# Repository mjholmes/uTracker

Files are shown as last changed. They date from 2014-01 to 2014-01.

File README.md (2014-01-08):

# uTracker - a micro RF tracker for HAB use

This tracker builds on the basic tracker i built about a year ago. It is based on an Arduino 328 and uses a bespoke PCB with surface mount components to achiever a much smaller form factor than the previous basic tracker.

The board makes use of a dc/dc step up converter providing 3.3v from a single AA/AAA battery. Unusually for smaller boards this uses the NTX2 / NTX2b for the RF transmitter.

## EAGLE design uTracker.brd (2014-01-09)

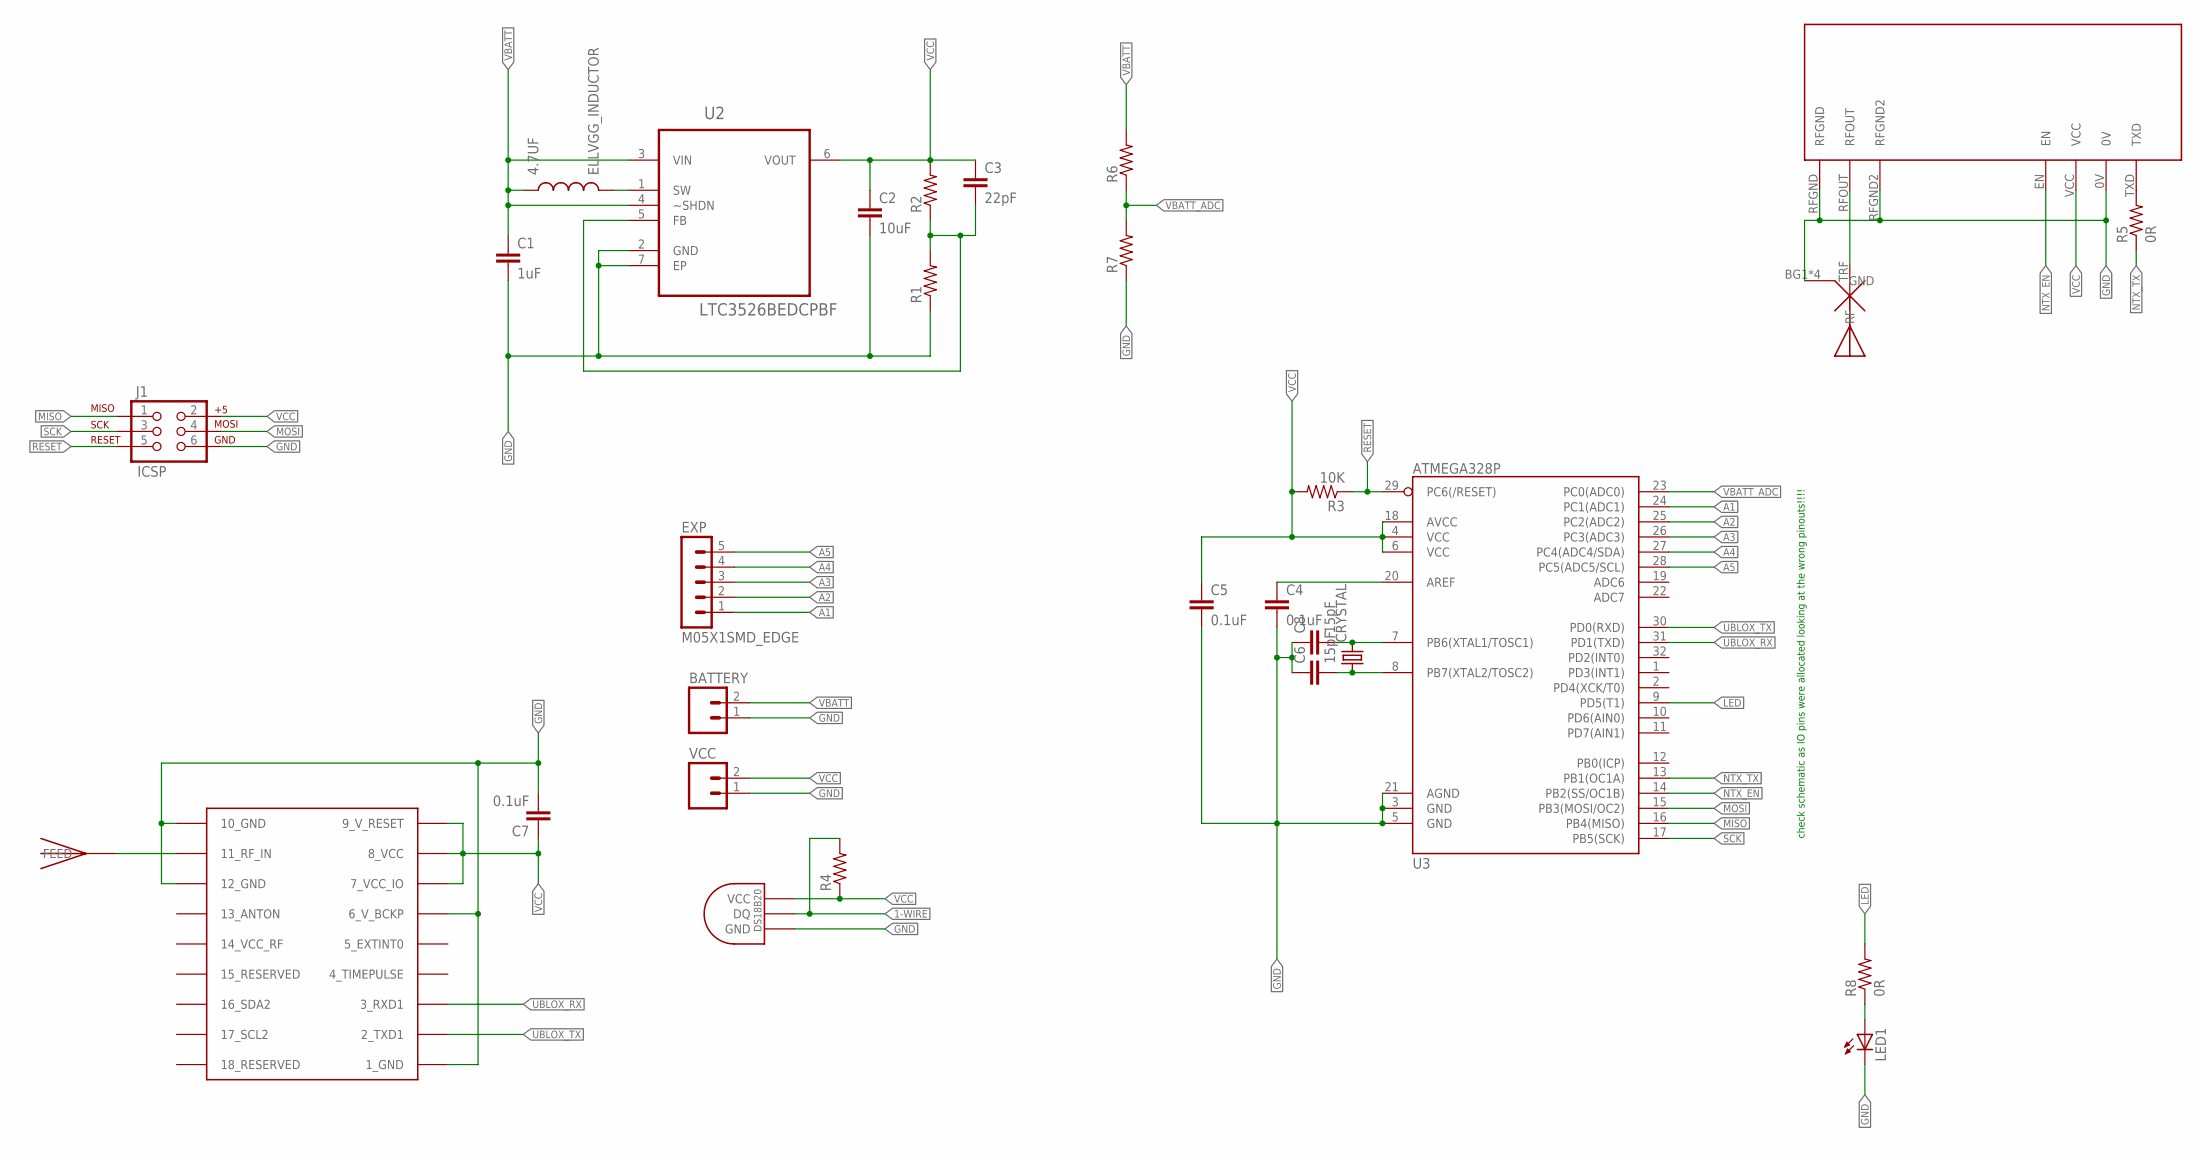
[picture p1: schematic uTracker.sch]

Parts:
4.7UF: ELLVGG_INDUCTOR
BATTERY: M02PTH; 1X02
C1: 1uF; 0805
C2: 10uF; 0805
C3: 22pF; 0805
C4, C5, C7: 0.1uF; 0805
C6, C8: 15pF; 0805
CRYSTAL: ABRACON_ABM3_CRYSTALABM03_HC49; ABM03_HC49
EXP: M05X1SMD_EDGE; M05_SMD_EDGE
J1: ICSP; ICSP_SMD_EDGE
LED1: LED1206; LED-1206
R1, R2, R4, R6, R7: RESISTOR0805-RES; 0805
R3: 10K; 0805
R5, R8: 0R; 0805
U2: LTC3526BEDCPBF; DFN200X200X80-7N
U3: ATMEGA328P; TQFP32-08
U$1: ANTENNA; ANTCONN_GNDPL
U$2: JTI_ANTENNA-1575AT43A40
U$3: NTX2
U$4: DS1820SOIC; DS18B20_SOIC
UBLOX: UBLOX_MAX-6
VCC: M02PTH; 1X02

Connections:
1-WIRE: R4.2, U$4.DQ
A1: EXP.1, U3.24 (PC1(ADC1))
A2: EXP.2, U3.25 (PC2(ADC2))
A3: EXP.3, U3.26 (PC3(ADC3))
A4: EXP.4, U3.27 (PC4(ADC4/SDA))
A5: EXP.5, U3.28 (PC5(ADC5/SCL))
GND: BATTERY.1, C1.2, C2.2, C4.2, C5.2, C6.1, C7.2, C8.1, J1.6, LED1.C, R1.1, R7.1, U2.2 (GND), U2.7 (EP), U3.3 (GND), U3.5 (GND), U3.21 (AGND), U$1.BG1 (GND), U$1.BG2 (GND), U$1.TG1 (GND), U$1.TG2 (GND), U$3.0V, U$3.RFGND, U$3.RFGND2, U$4.GND, UBLOX.1_GND, UBLOX.6_V_BCKP, UBLOX.10_GND, UBLOX.12_GND, VCC.1
LED: R8.2, U3.9 (PD5(T1))
MISO: J1.1, U3.16 (PB4(MISO))
MOSI: J1.4, U3.15 (PB3(MOSI/OC2))
unnamed: C3.2, R1.2, R2.1, U2.5 (FB)
unnamed: U$2.FEED, UBLOX.11_RF_IN
unnamed: 4.7UF.P$2 (2), U2.1 (SW)
unnamed: C4.1, U3.20 (AREF)
unnamed: R5.2, U$3.TXD
unnamed: C8.2, CRYSTAL.2, U3.7 (PB6(XTAL1/TOSC1))
unnamed: C6.2, CRYSTAL.1, U3.8 (PB7(XTAL2/TOSC2))
unnamed: U$1.TRF (RF), U$3.RFOUT
unnamed: LED1.A, R8.1
NTX_EN: U3.14 (PB2(SS/OC1B)), U$3.EN
NTX_TX: R5.1, U3.13 (PB1(OC1A))
RESET: J1.5, R3.1, U3.29 (PC6(/RESET))
SCK: J1.3, U3.17 (PB5(SCK))
UBLOX_RX: U3.31 (PD1(TXD)), UBLOX.3_RXD1
UBLOX_TX: U3.30 (PD0(RXD)), UBLOX.2_TXD1
VBATT: 4.7UF.P$1 (1), BATTERY.2, C1.1, R6.2, U2.3 (VIN), U2.4 (~SHDN)
VBATT_ADC: R6.1, R7.2, U3.23 (PC0(ADC0))
VCC: C2.1, C3.1, C5.1, C7.1, J1.2, R2.2, R3.2, R4.1, U2.6 (VOUT), U3.4 (VCC), U3.6 (VCC), U3.18 (AVCC), U$3.VCC, U$4.VCC, UBLOX.7_VCC_IO, UBLOX.8_VCC, UBLOX.9_V_RESET, VCC.2

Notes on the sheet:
check schematic as IO pins were allocated looking at the wrong pinouts!!!!

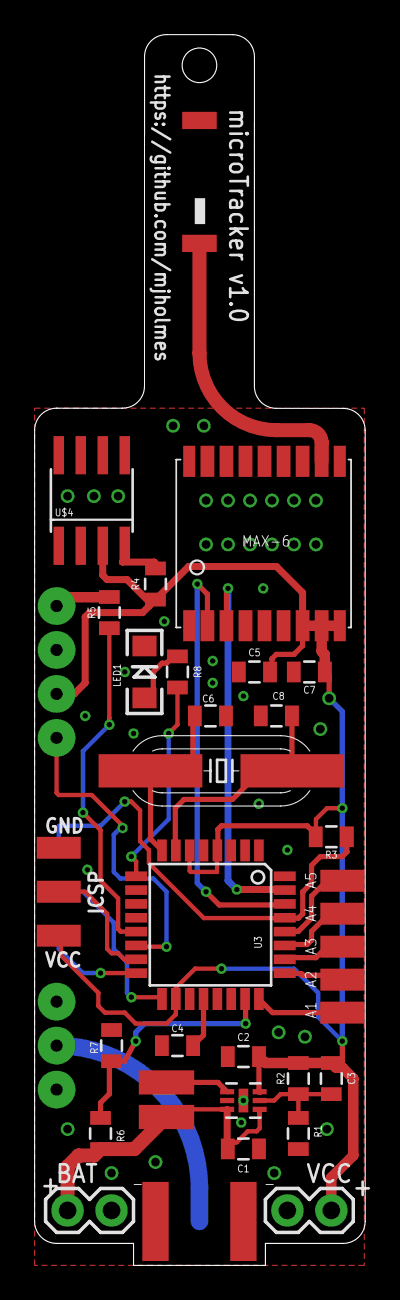
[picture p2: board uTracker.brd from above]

Board: 2 copper layers, 19.1 x 71.1 mm, 30 parts (1 on the bottom side), 28 nets.

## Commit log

2014-01-09 Final for v1.0
    [uTracker.brd]
2014-01-09 Modified ICSP header to match 0.1" spacing
    This should ease programming by allowing a standard 2x3 0.1" header to
    be clipped on the side of the board.
    [uTracker.brd, uTracker.sch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]

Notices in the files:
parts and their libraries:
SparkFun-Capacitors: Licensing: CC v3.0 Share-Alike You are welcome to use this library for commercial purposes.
